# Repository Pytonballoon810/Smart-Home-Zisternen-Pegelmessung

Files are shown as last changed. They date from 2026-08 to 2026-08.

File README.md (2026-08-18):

# Zisternen-Pegelmessung

Continuous water level measurement for a garden cistern, using a hydrostatic
4–20 mA probe read by an ESP8266 and reported to Home Assistant via ESPHome.

Replaces a ten-contact float ladder that resolved 300 litres per step — too
coarse to answer the question that actually matters: *is there enough water for
tomorrow's irrigation, and how fast does the tank recover?*

---

## How it works

A 2-wire loop-powered probe sits near the bottom of the shaft and pushes 4 mA
when the water column is zero, 20 mA at full range. That current runs through a
100 Ω burden resistor, turning it into 0.400 V … 2.000 V, which a 16-bit
ADS1115 reads over I²C. ESPHome converts volts to centimetres, then to litres.

The reason for 4–20 mA rather than a voltage output: **a broken cable reads
0 mA, which is 0.000 V — clearly distinguishable from an empty tank at 4 mA.**
A voltage sensor cannot tell those apart, and a cistern that reports "empty"
because a mouse chewed the cable is worse than no sensor at all.

| State | Current | Voltage |
|---|--:|--:|
| Cable break | 0 mA | 0.00 V |
| Empty | 4 mA | 0.40 V |
| Full | 20 mA | 2.00 V |
| Short / overrange | 30 mA | 3.00 V |

---

## Repository layout

| Path | Contents |
|---|---|
| [`docs/hardware.md`](docs/hardware.md) | Bill of materials, wiring, how to choose a probe, installation in the shaft |
| [`docs/pcb-specification.md`](docs/pcb-specification.md) | Interface board: circuit, rationale, v1.0 → v1.1 change log |
| [`docs/calibration.md`](docs/calibration.md) | Two-point calibration procedure — **do not skip this** |
| [`docs/home-assistant.md`](docs/home-assistant.md) | Entities, dashboard cards, derived sensors, automations |
| [`docs/findings.md`](docs/findings.md) | Measured behaviour of an open-bottomed cistern |
| [`esphome/`](esphome/) | Device configuration and secrets template |
| [`hardware/`](hardware/) | KiCAD project, custom libraries, fabrication outputs |
| [`images/`](images/) | Photographs (shot list only — nothing built yet) |

---

## Status

| Part | State |
|---|---|
| ESPHome configuration | Written, not yet flashed |
| Interface PCB | Designed, routed, ERC/DRC clean — **not yet fabricated** |
| Probe and installation | Not yet purchased or built |
| Calibration | Pending installation |

Nothing here has been through a full build yet. The findings in
[`docs/findings.md`](docs/findings.md) come from the float ladder this project
replaces, not from the probe.

---

## Before you build one of these

**Get a vented probe.** The cable must contain a capillary venting the sensor
to atmosphere. Without it the probe measures water column *plus* barometric
pressure, and a normal weather system moves that by 20–30 cm of apparent water
— hundreds of litres of error that drifts rather than breaks. This is the single
most expensive mistake available here.

**The burden resistor sets your accuracy.** 100 Ω at 0.1 % and ≤50 ppm/K. A 1 %
part dominates every other error in the chain, including the probe's own.

**Calibrate in two points after installation.** The shipped transfer curve is
theoretical. Ten minutes with a multimeter and a tape measure is the difference
between an indication and a measurement.

**The v1.1 board has no input protection.** No fuse, no reverse-polarity diode,
no TVS — deliberately, to keep the part count at eight. Feed it from a
known-good supply and check polarity at J1. See §14 of the PCB specification
for what to reinstate if your installation is less forgiving than a dry shed.

---

## An honest caveat about open-bottomed cisterns

This cistern has an open bottom, in hydraulic contact with groundwater. That
makes it a **buffer, not a reservoir**: the level settles at the groundwater
table, rainfall above that drains away within hours, and the tank refills itself
after heavy draw-off. Measured recovery was roughly 600 litres in five hours.

The practical consequence is that usable storage is not the tank volume but the
gap between groundwater level and full — and that gap moves with the season, so
a fixed "ration below X litres" rule does not work.

[`docs/findings.md`](docs/findings.md) has the measurements. If your cistern is
sealed, none of it applies.

Groundwater abstraction is also regulated in most jurisdictions — in Germany
under the Wasserhaushaltsgesetz. Worth asking your local authority before
building something similar.

---

## Licence

Not yet chosen. Until one is added, treat this as "look, learn, but ask before
redistributing".

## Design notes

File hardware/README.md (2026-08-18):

# KiCAD project

The interface board itself. **The design is documented in
[`../docs/pcb-specification.md`](../docs/pcb-specification.md)** — circuit,
BOM, rationale and the v1.0 → v1.1 change log. This file covers only the
mechanics of working with the KiCAD project.

## Status

| Stage | State |
|---|---|
| Schematic | ERC **0 errors, 0 warnings** |
| Netlist | Verified against intent (8 nets) |
| Placement | No courtyard overlaps |
| Routing | 68 segments, 6 vias, **0 unconnected** |
| DRC | **0 errors** (5 cosmetic silkscreen warnings) |
| Fabrication outputs | Gerbers, drill, BOM, PDFs in `output/` |

The silkscreen warnings are U2's outline crossing the board edge, which is the
deliberate antenna overhang, plus reference designators overlapping the
connector labels.

## Layout

```
hardware/
  cistern-level-interface.kicad_pro   project (also carries the DRC floor)
  cistern-level-interface.kicad_sch   schematic
  cistern-level-interface.kicad_pcb   board
  fp-lib-table, sym-lib-table         point at lib/ — needed for the custom parts
  lib/cistern.kicad_sym               ADS1115_Breakout, MP1584_Module symbols
  lib/cistern.pretty/                 MP1584EN_Buck_Module footprint
  output/                             generated: Gerbers, drill, BOM, PDFs, render
```

`lib/cistern.pretty/Fuse_Bourns_MF-R025_Radial.kicad_mod` is unused in v1.1. It
is kept because the protected variant in the change log would need it.

## Custom parts

Both module footprints were built from the physical hardware, not datasheets:

- **MP1584EN** — 22.3 × 16.8 mm, four corner connections each doubled on
  2.54 mm pitch (8 holes), columns 19.05 mm apart. Top view: IN left, OUT
  right, `+` is the lower hole of each pair. Pad pitch still wants a caliper
  check before ordering.
- **ADS1115 (KY-053)** — plain 1×10 header on 2.54 mm, order VDD, GND, SCL,
  SDA, ADDR, ALRT, A0, A1, A2, A3. Confirmed against the module.

## Regenerating outputs

```bash
kicad-cli sch export pdf -o output/cistern-level-interface-schematic.pdf cistern-level-interface.kicad_sch
kicad-cli pcb export gerbers -o output/gerbers cistern-level-interface.kicad_pcb
kicad-cli pcb export drill -o output/gerbers/ cistern-level-interface.kicad_pcb
kicad-cli pcb drc --severity-error cistern-level-interface.kicad_pcb
```

## Re-routing

Routed with the [KiCADRoutingTools](https://github.com/drandyhaas/kicadroutingtools)
plugin, headless:

```bash
python route.py in.kicad_pcb out.kicad_pcb --layers F.Cu B.Cu --clearance 0.2 --track-width 0.25 --via-size 0.6 --via-drill 0.3 --power-nets "*GND*" "*19V*" "*5V*" "*3V3*" --power-nets-widths 0.8 0.8 0.5 0.5
```

Two rules from the plugin's own docs that are easy to get wrong:

- Copy boards with its `copy_board.py`, not `cp`. A bare copy strands the
  sibling `.kicad_pro` that carries the DRC floor, and KiCAD then grades
  correct copper as phantom violations.
- Route to a **fresh** output path each run. Re-using one makes `route.py` read
  back its own `.kicad_pro` and silently change the result.

Verify with all three — they check different things:

```bash
python check_connected.py out.kicad_pcb
python check_drc.py out.kicad_pcb --clearance 0.2 --clearance-margin 0.1
kicad-cli pcb drc --severity-error out.kicad_pcb
```

A DRC-clean board can be entirely disconnected; isolated copper has no
clearance conflicts.

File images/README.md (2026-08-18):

# Images

Empty for now — the installation is not built yet.

## Shot list

Photographs worth taking as the build progresses. Each answers a question that
text handles badly.

### Probe and shaft

- [ ] **Probe with the protective cap removed**, showing the diaphragm.
      Answers "which end actually measures" — the reference point for depth
      measurement during calibration.
- [ ] **Cable cross-section**, showing the capillary between the conductors.
      This is the detail people get wrong when buying; a photo settles it.
- [ ] **Probe suspended in the stilling tube**, before lowering.
      Shows the 20–30 cm standoff from the floor.
- [ ] **Shaft from above** with the probe installed and the junction box
      mounted near the top.

### Junction box

- [ ] **Interior**, showing where the capillary terminates and the
      pressure-equalising filter sits.
- [ ] **Mounting position** relative to the maximum water level.

### Electronics

- [ ] **Breadboard prototype** — useful precisely because it is untidy; it
      shows the circuit is only a handful of components.
- [ ] **Assembled interface board**, with both modules seated, before it goes
      in the enclosure.
- [ ] **MP1584 trimpot being set to 5.0 V** with the meter reading visible and
      the D1 mini socket still empty. This is the step that kills the ESP if
      done in the wrong order, so it is worth documenting.
- [ ] **Enclosure interior**, with terminal blocks, modules and the burden
      resistor visible.
- [ ] **Close-up of the burden resistor** with its markings legible.

### Home Assistant

- [ ] **Dashboard card** with a real level reading.
- [ ] **72-hour history graph** covering an irrigation cycle and the refill
      afterwards. This is the single most informative screenshot for anyone
      with an open-bottomed cistern — it shows the recovery curve directly.
- [ ] **Calibration**: multimeter across R1, ideally with the reading visible.

## Conventions

- Landscape, 1600 px wide is plenty
- Compress before committing; a repo does not need 4 MB photos
- Descriptive filenames: `probe-diaphragm.jpg`, not `IMG_2847.jpg`
- Reference from the docs as `![description](../images/filename.jpg)`

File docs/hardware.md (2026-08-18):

# Hardware

Bill of materials, wiring, and selection criteria.

---

## 1. Bill of materials

### Measurement chain

| Item | Specification | Qty | ~Cost |
|---|---|--:|--:|
| **Level probe** | 4–20 mA, 2-wire, 12–32 V DC, range to suit, stainless, IP68, **vented cable** | 1 | 40 € |
| **ADC module** | ADS1115, 16-bit, I²C (Joy-IT KY-053, sold as RB-ADC01) | 1 | 12 € |
| **Microcontroller** | ESP8266 (Wemos D1 mini) | 1 | 5–8 € |
| **Buck converter** | MP1584EN adjustable module, set to 5.0 V | 1 | 2 € |
| **Burden resistor** (R1) | 100 Ω, 0.1 %, metal film, ≤ 50 ppm/K, ≥ 0.25 W | 1 | 2 € |
| **Series limiter** (R2) | 1 kΩ, 1 %, 0402 — non-critical | 1 | <1 € |
| **Filter cap** (C3) | 100 nF C0G, 0805 | 1 | <1 € |
| **Interface PCB** | 70 × 60 mm, 2-layer — see [`pcb-specification.md`](pcb-specification.md) | 1 | ~5 € (qty 5) |
| **Power supply** | 19 V DC, ≥ 300 mA | 1 | 12–20 € |

The three discrete parts, two screw terminals and the two module sockets sit on
the interface PCB. On a breadboard, only R1 is strictly needed — see §3.

### Cable run (if the probe cable is too short)

| Item | Specification | Qty | ~Cost |
|---|---|--:|--:|
| **Junction box with pressure equalisation** | e.g. TECSON T12080, IP 64, Goretex filter | 1 | 27 € |
| Extension cable | 2-core, ≥ 0.4 mm² | as needed | 5 € |

### Installation

| Item | Specification | Qty | ~Cost |
|---|---|--:|--:|
| Stilling tube | HT pipe DN 50/75, drilled | ~2 m | 10 € |
| Pipe clamps | for shaft wall | 2–3 | 5 € |
| Suspension | stainless wire or UV-resistant ties | 1 | 3 € |
| Enclosure | IP65 | 1 | 15 € |
| Terminal blocks, glands, wire | — | 1 set | 10 € |

**Total: approximately 140 €.**

---

## 2. Choosing the probe

### Measurement range

Measure the **water column**, not the cistern's build height:

```
range = (overflow height) − (pump intake height)
```

A 3 m deep cistern typically has 2.2–2.5 m of usable column — the overflow sits
20–40 cm below the ceiling, the pump 20–30 cm above the floor.

Pick the next size up, not two. Accuracy is specified as a percentage of **full
scale**: 0.5 % on a 2 m probe is 10 mm, on a 5 m probe it is 25 mm.

Exceeding the range does not damage the probe — most tolerate several times
their rated pressure. The reading simply stops rising.

### Vented cable — mandatory

The specification must state one of:

- Luftführungskabel
- vented cable / air tube
- capillary / Kapillare
- gauge pressure (as opposed to absolute)

**Without it the probe measures absolute pressure**, i.e. water column *plus*
atmospheric pressure. A normal weather system moves barometric pressure by
20–30 hPa, equivalent to 20–30 cm of water column. In a 2 m diameter cistern
that is 600–900 litres of error.

The failure mode is insidious: nothing breaks, the reading just wanders slowly.

### Cable length

Measure from the intended probe position to the dry termination point, then add
two metres. Vented cable cannot be extended with ordinary connectors — the air
path must stay open. Either buy it long enough, or budget for a junction box
with a pressure-equalising filter.

### Material

Stainless 304 is adequate for rainwater. 316L only matters if chlorides are
present.

Prefer a **removable protective cap** — an open-bottomed cistern carries
sediment, and being able to clean the diaphragm without pulling the probe is
worth having.

---

## 3. Wiring

Minimum wiring, as on the breadboard prototype:

```
   19 V (+) ─────────────────────────────►  Probe (+)     [usually red]

   Probe (−) [usually black] ──┬─────────►  ADS1115  A0
                               │
                            R1 100 Ω
                               │
   19 V (−) ───────────────────┴─────────►  ADS1115  GND ──── ESP GND

   ESP 3V3 ──────────────────────────────►  ADS1115  VDD
   ESP D2 (GPIO4) ───────────────────────►  ADS1115  SDA
   ESP D1 (GPIO5) ───────────────────────►  ADS1115  SCL
```

The interface PCB adds two parts to this chain — **R2**, a 1 kΩ series resistor
between the burden node and A0, and **C3**, 100 nF from A0 to ground. Neither
affects the measurement: R2 limits current into the ADS1115's internal
protection diodes, and C3 filters the buck converter's switching noise. R2 sits
in a 1 kΩ : ~6 MΩ divider with the ADC input, contributing about 0.02 % gain
error, which the two-point calibration removes anyway. On a breadboard both can
be omitted.

The PCB also carries the MP1584 buck that derives 5 V for the ESP, so only one
supply is needed.

**Common ground is mandatory.** The ADS1115 measures against its own GND pin;
if that is not tied to the supply negative, the reading is undefined.

### Signal levels at 100 Ω

| State | Current | Voltage |
|---|--:|--:|
| Cable break | 0 mA | 0.00 V |
| Empty (probe top) | 4 mA | 0.40 V |
| Half (mid-range) | 12 mA | 1.20 V |
| Full (range top) | 20 mA | 2.00 V |
| Short / overrange | 30 mA | 3.00 V |

### Why 100 Ω and not 150 Ω

The ADS1115 input must stay below VDD + 0.3 V. Powered from 3.3 V that ceiling
is 3.6 V.

| Burden | Signal at 20 mA | Fault at 30 mA |
|---|--:|--:|
| 100 Ω | 2.00 V | 3.00 V ✅ |
| 150 Ω | 3.00 V | **4.50 V** ❌ |

150 Ω works if the ADS1115 runs at 5 V — but then the I²C bus sits at 5 V
against a 3.3 V microcontroller, which needs a level shifter. The extra
resolution is meaningless: both options resolve far finer than the probe.

### Supply voltage

The probe needs its minimum terminal voltage *plus* the burden drop:

```
supply ≥ probe_minimum + (0.020 A × burden)
       ≥ 12 V + 2 V  =  14 V
```

**This installation uses 19 V**, which leaves 17 V at the probe at full scale —
comfortable margin over the 12 V minimum, and within the MP1584's 4.5–28 V
input range. A surplus laptop brick is ideal; they are almost all 19 or 19.5 V
and rated far beyond the ~300 mA needed.

> ### ⚠ Check polarity before connecting
>
> The interface board has **no reverse-polarity protection** — the series
> Schottky was dropped in v1.1 to cut part count. Reversing J1 destroys the
> MP1584 and probably everything downstream of it.
>
> Laptop supplies often have **three** output conductors: V+, V− and a thin
> ID/sense wire the laptop uses to identify the adapter. Identify them with a
> meter before wiring — the pair reading ≈19 V DC are your rails, and the wire
> that floats or reads an odd, drifting voltage is the ID line, which is left
> unconnected. Check on **AC volts** too: any significant AC means it is a
> transformer, not a DC supply, and must not be connected.

---

## 4. Installation in the shaft

**Suspend the probe 20–30 cm above the floor**, do not rest it on the bottom.
Sediment accumulates, and a probe lying in silt eventually measures silt.

**Use a stilling tube** — a drilled HT pipe. It holds the probe in position and
shields it from flow when the pump runs.

**Terminate the cable dry.** The capillary's open end must sit in dry air, with
desiccant if the enclosure is not otherwise dry. If the run needs a junction in
the shaft, use a box with a pressure-equalising filter; an ordinary sealed box
would block the air path and defeat the vented cable entirely.

**Define zero at the pump intake**, not at the floor. Water below the intake
cannot be pumped and should not appear as available stock.

---

## 5. Litres per centimetre

```
litres_per_cm = π × (diameter / 2)² × 10
```

| Diameter | Area | Litres per cm |
|---|--:|--:|
| 1.5 m | 1.77 m² | 17.7 |
| 1.8 m | 2.54 m² | 25.4 |
| 2.0 m | 3.14 m² | 31.4 |
| 2.2 m | 3.80 m² | 38.0 |
| 2.5 m | 4.91 m² | 49.1 |

For non-cylindrical tanks, substitute the cross-sectional area. The ESPHome
configuration does this calculation from a `substitutions` entry — no code
changes needed.

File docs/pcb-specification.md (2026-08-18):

# PCB Specification — Cistern Level Sensor Interface

Interface board carrying the ESP8266 and ADS1115 modules, the burden resistor
and a 19 V to 5 V converter. Replaces the breadboard prototype for permanent
installation.

**Version:** 1.1 — 18 August 2026
**Status:** built, routed, ERC and DRC clean. Not yet fabricated.
**KiCAD project:** [`../hardware/`](../hardware/)

> **v1.1 is a deliberate simplification of v1.0.** The original specification
> called for a full input-protection chain and a split analogue/digital ground.
> Both were dropped. Section 14 records what changed and why — read it before
> assuming a part exists.

---

## 1. Purpose and scope

Carrier board that interfaces a 4–20 mA hydrostatic level probe to an ESP8266
running ESPHome, replacing the breadboard prototype for permanent installation
in a garden shed.

**Out of scope:** the probe, the junction box at the cistern shaft, the
enclosure, and external wiring.

### 1.1 Design philosophy

The board is a **carrier for three off-the-shelf modules**, not an integrated
design:

- Hand-solderable, no reflow or fine-pitch work
- Modules are individually replaceable if damaged in the field
- Avoids RF layout, antenna matching and USB design for the ESP
- Total assembly time under 30 minutes

This costs board area versus an integrated design. For a one-off in a shed,
that trade is worth making.

---

## 2. Functional requirements

| ID | Requirement | v1.1 |
|---|---|---|
| F1 | Accept a 2-wire 4–20 mA loop-powered probe, 12–32 V DC compliance | ✅ met |
| F2 | Convert loop current to a voltage readable by a 16-bit ADC | ✅ met |
| F3 | Single-supply operation from one DC input | ✅ met (19 V) |
| F4 | Distinguish cable break (0 mA) from empty tank (4 mA) | ✅ met |
| F5 | Survive a probe short circuit (≥ 30 mA) without damage | ⚠️ partial — see §5.3 |
| F6 | Survive reverse polarity on the input without damage | ❌ **descoped** |
| F7 | Break out unused ADC channels for future expansion | ❌ descoped |
| F8 | Provide test points for two-point calibration in situ | ❌ descoped — probe R1 directly |

F5 is partial rather than failed: a 30 mA probe fault still produces only 3.0 V
at the burden, which the ADS1115 tolerates (§3.3). What is gone is protection
against surge and gross overvoltage.

---

## 3. Electrical specification

### 3.1 Supply

| Parameter | Value |
|---|---|
| Input voltage | 19 V DC nominal (4.5–28 V accepted by U1) |
| Input current | ~100 mA typical, 300 mA supply recommended |
| Reverse polarity | **Not protected** |
| Internal rails | 5 V (MP1584 buck), 3.3 V (D1 mini onboard LDO) |

### 3.2 Measurement chain

| Parameter | Value |
|---|---|
| Loop current range | 4–20 mA (0–30 mA without damage) |
| Burden resistor | 100 Ω, 0.1 %, ≤ 50 ppm/K, ≥ 0.25 W |
| Signal at burden | 0.400 V (4 mA) … 2.000 V (20 mA) |
| Fault signal | 0.000 V (break), 3.000 V (30 mA short) |
| ADC | ADS1115, 16 bit, gain ±4.096 V, 125 µV/LSB |
| Effective resolution | ≈ 12 800 counts over range |

> **The burden resistor sets system accuracy.** Its tolerance appears directly
> in the reading. A 1 % part would dominate the probe's own 0.2–0.5 % error.
> Metal film, not carbon — carbon drifts up to 1000 ppm/K and the shed sees
> −10 to +40 °C.

### 3.3 ADC supply decision

**ADS1115 runs from 3.3 V, not 5 V.**

Its input must stay below VDD + 0.3 V. At 3.3 V that ceiling is 3.6 V; the
worst-case fault signal is 3.0 V, leaving 0.6 V of margin. Running from 3.3 V
also puts the I²C bus natively at ESP level, so **no level shifter is
required**.

Running the ADC at 5 V would allow a 150 Ω burden and marginally better
resolution, at the cost of a level shifter or an out-of-spec I²C connection.
The extra resolution is meaningless — the probe is two orders of magnitude
coarser than either option.

---

## 4. Block diagram

```
  19 V DC in (J1)
      │
      ├──────────────────────────────────► J2.1  Probe (+)  [LOOP+]
      │
   [U1  MP1584EN buck 19→5 V]
      │
      5 V ──► D1 mini (5V pin) ──► onboard LDO ──► 3.3 V ──► ADS1115 VDD
                    │                                            │
                    └──────────── I²C (SDA/SCL, 3.3 V) ──────────┘
                                                                 │
  J2.2  Probe (−) ──┬────── [R2 1 k] ──┬──────────────────► ADS1115 A0
     [LOOP-]        │                  │
                 [R1 100 Ω]        [C3 100 nF]
                    │                  │
                   GND ──────────────  GND
```

Single ground net, poured on both layers — see §10.

---

## 5. Circuit detail

### 5.1 Input

No protection components. J1 feeds U1's input and J2.1 directly.

> **This is the deliberate compromise of v1.1.** There is no fuse, no series
> diode and no TVS. Feed the board only from a known-good 19 V supply and check
> polarity at J1 before every power-up. If the board is ever moved somewhere
> with a long buried supply run, revisit §14.

### 5.2 Buck converter

**U1 — MP1584EN adjustable module**, 4.5–28 V in, adjustable out, ~3 A capable.

> ### ⚠ Set U1 to 5.0 V before fitting U2
>
> The MP1584's output is set by a multi-turn trimpot, and the as-shipped
> setting is arbitrary — often well above 5 V. Power the board with the D1 mini
> socket **empty**, set the output to 5.0 V with a meter, then fit the ESP.
> This is silkscreened on the board.

A 7805 linear regulator will not do: 19 V in, 5 V out at 200 mA is 2.8 W of
dissipation in a sealed enclosure.

### 5.3 Measurement front end

| Ref | Part | Function |
|---|---|---|
| R1 | 100 Ω, 0.1 %, ≤50 ppm/K, 0.25 W metal film, axial | **Burden** — converts loop current to voltage |
| R2 | 1 kΩ, 1 %, 0402 | Series limit into the ADC's internal protection diodes |
| C3 | 100 nF, C0G, 0805 | Anti-alias / buck-noise filter, τ = 100 µs with R2 |

R2 and C3 form a low-pass at 1.6 kHz. The signal is quasi-static — a cistern
level changes over hours — so this costs nothing and removes switching noise
from the buck. That matters more here than it would have with the v1.0 Recom
module: the MP1584 is a noisier switcher.

**Neither R2 nor C3 affects accuracy.** R2 sits in a 1 kΩ : ~6 MΩ divider with
the ADS1115 input, contributing about 0.02 % gain error — and that is a
systematic gain term, which the two-point `calibrate_linear` removes outright.
R2 carries under a microamp and dissipates around a nanowatt, so its tolerance,
dielectric and power rating are all irrelevant. R1 is the opposite in every
respect.

---

## 6. Connectors and interfaces

| Ref | Type | Pins | Function |
|---|---|---|---|
| J1 | Screw terminal, 5.08 mm | 2 | 19 V DC input — silkscreened `+19V` / `GND` |
| J2 | Screw terminal, 5.08 mm | 2 | Probe loop — silkscreened `LOOP+` / `LOOP−` |
| U1 | Module, 8 holes in 4 corner pairs | — | MP1584EN buck |
| U2 | Socket header, 2 × 1×8 | 16 | D1 mini |
| U3 | Socket header, 1×10 | 10 | KY-053 ADS1115, `VDD` and `A3` ends marked |

> **J2 polarity is silkscreened**, and it matters: the probe is 2-wire loop
> powered, and reversing it reads 0 mA — indistinguishable from a cable break
> at the ESPHome level.

### 6.1 Module orientation

**U3's body overhangs one side of its header** by about 15 mm. It must face
*away* from U2 — there is only 7.4 mm of clearance toward the ESP but 22 mm on
the other side, where it passes over R1/R2/C3, all low enough to sit under a
socketed module. The board is silkscreened `U3 BODY THIS SIDE (NOT TOWARD U2)`.

**U2's body overhangs the top board edge** by about 5 mm, deliberately: that is
the antenna end, and copper is kept clear beneath it.

---

## 7. Bill of materials

| Ref | Part | Package | Qty | Notes |
|---|---|---|--:|---|
| U1 | MP1584EN buck module | 22.3 × 16.8 mm, 8 THT holes | 1 | **Set to 5.0 V first** |
| U2 | Wemos D1 mini (ESP8266) | Module on sockets | 1 | |
| U3 | Joy-IT KY-053 (ADS1115) | Module on 1×10 socket | 1 | Also sold as RB-ADC01 |
| R1 | 100 Ω, 0.1 %, ≤50 ppm/K | Axial DIN0207, 10.16 mm | 1 | **Accuracy-critical** |
| R2 | 1 kΩ, 1 % | 0402 | 1 | Non-critical |
| C3 | 100 nF, C0G | 0805 | 1 | |
| J1, J2 | Screw terminal 5.08 mm | 2-pin | 2 | |
| H1–H4 | M3 mounting holes | 3.2 mm | 4 | NPTH |

Eight placed parts. Estimated component cost excluding the three modules:
**under 5 €.**

---

## 8. Mechanical

| Parameter | Value |
|---|---|
| Board outline | 70 × 60 mm |
| Thickness | 1.6 mm |
| Mounting | 4 × M3, 3.2 mm dia., 5 mm in from each corner |
| Component height | ≤ 20 mm (D1 mini on sockets is tallest) |
| Connector edge | J1 and J2 along one long edge for cable entry |

Terminal blocks on a single edge simplify cable glanding — the enclosure needs
penetrations on one side only.

---

## 9. Fabrication

| Parameter | Specification |
|---|---|
| Layers | 2 |
| Material | FR-4, TG 130 or better |
| Copper weight | 1 oz (35 µm) |
| Min trace / space | 0.25 mm signal, 0.2 mm clearance |
| Min drill | 0.3 mm (vias), 1.0 mm (module holes) |
| Surface finish | HASL lead-free, or ENIG |
| Solder mask | Green, both sides |
| Silkscreen | White, top side |

Within standard capability at JLCPCB, Aisler and PCBWay. No controlled
impedance, no blind or buried vias, no special stackup.

**Quantity:** 5 pieces is the typical minimum and costs about the same as 1–2.

Gerbers and drill files are exported to
[`../hardware/output/gerbers/`](../hardware/output/gerbers/).

---

## 10. Layout, as routed

| Parameter | Value |
|---|---|
| Signal tracks | 0.25 mm |
| GND, +19 V | 0.8 mm |
| +5 V, +3V3 | 0.5 mm |
| Vias | 0.6 mm outer / 0.3 mm drill, 6 used |
| Clearance | 0.2 mm |
| Segments | 68 |

Routed with the [KiCADRoutingTools](https://github.com/drandyhaas/kicadroutingtools)
plugin's headless `route.py`.

**Ground is a single net, poured on both F.Cu and B.Cu.** v1.0 called for split
AGND/DGND joined at a star point; §14 explains why that was dropped.

Layout intent worth preserving if the board is ever re-laid:

1. Analogue parts (R1, R2, C3, U3) grouped in one corner, ≥ 15 mm from the ESP
   antenna. As built the separation is over 30 mm.
2. No copper under the D1 mini's antenna, which overhangs the top edge.
3. Keep the ground pour continuous between U3 and R1 — it is what makes the
   return path short (§11).

---

## 11. Grounding

The v1.0 concern was that the burden's return current would share a narrow
ground **trace** with the ESP: 200 mA of WiFi burst through 10 mΩ of shared
copper is 2 mV, or 0.12 % of full scale — comparable to the probe's entire
tolerance, given away by a layout shortcut. v1.0 answered it with separate AGND
and DGND pours joined by a 0 Ω link at the buck output.

v1.1 answers it with a **solid pour on both layers** instead. Return current in
a plane concentrates under its own outgoing trace, and the spreading resistance
between U2's ground and the analogue corner is well under a milliohm —
roughly 0.1 mV at 200 mA, some twenty times better than the trace case. The
star-point resistor became redundant and was removed.

The consequence: **do not fragment the pour** between U3 and R1. The plane is
doing the work the star link used to.

---

## 12. Verification

### 12.1 Board bring-up, before fitting modules

| Step | Check | Pass criteria |
|---|---|---|
| 1 | Visual, solder bridges | None |
| 2 | Resistance J1+ to J1− | > 10 kΩ (no short) |
| 3 | Apply 19 V, measure U1 output | Adjust trimpot to 5.00 V ± 0.05 V |
| 4 | Confirm 5 V at U2's 5V socket pin | 4.95–5.05 V |

**Step 3 is not optional and must precede fitting U2.**

### 12.2 With modules fitted

| Step | Check | Pass criteria |
|---|---|---|
| 5 | I²C scan in ESPHome log | Device found at 0x48 |
| 6 | Inject 4.00 mA into J2 | 0.400 V across R1 ± 0.5 mV |
| 7 | Inject 20.00 mA into J2 | 2.000 V across R1 ± 2 mV |
| 8 | Open J2 | 0 V across R1, fault sensor active |

Steps 6–7 need a current source; a bench supply with current limit and a series
ammeter is adequate. If unavailable, substitute a precision resistor across the
loop and calculate.

### 12.3 Calibration after installation

Two-point, measuring across R1 — see [`calibration.md`](calibration.md). This
corrects burden tolerance, probe offset and ADC gain error in one step. **Do not
skip it** — the theoretical curve is a starting point, not a calibration.

---

## 13. Open items

| Item | Notes |
|---|---|
| U1 pad pitch | Reconstructed from a photo of the actual module (22.3 × 16.8 mm, corner pairs on 2.54 mm, columns 19.05 mm apart). **Confirm with calipers before ordering.** |
| Enclosure selection | Determines final mounting |
| Cistern inner diameter | Needed for litre conversion, not for the PCB |
| Probe intake height | Defines zero point, not for the PCB |

U3's pinout was confirmed against the physical module and is no longer open.

---

## 14. What changed from v1.0, and why

v1.0 specified 21 placed parts on an 80 × 60 mm board. v1.1 has 8 on 70 × 60 mm.
The driver was a deliberate decision to let the modules do the work and keep
only what earns its place.

| Dropped | v1.0 rationale | Why it went |
|---|---|---|
| F1 PTC, D1 Schottky | Fault current limit, reverse polarity | Supply is a known-good brick in a dry shed; polarity is silkscreened and checked at commissioning |
| D2 TVS 33 V, D3 TVS 5 V | Surge from the buried probe cable | Accepted risk. **The one to reinstate first** if the board ever sees a long outdoor run |
| C1 100 µF, C2 100 nF | Bulk and HF decoupling | Redundant — the MP1584 module carries its own input and output capacitors |
| R3 0 Ω star link | Single AGND↔DGND connection | Superseded by the solid two-layer pour (§11) |
| TP1–TP4 | In-situ calibration points | R1 is an axial part; its leads take meter probes directly |
| J3 spare ADC breakout | F7 future expansion | Not needed; A1–A3 remain unconnected at U3 |
| J4 I²C expansion header | Future sensors | Not needed |

| Changed | v1.0 | v1.1 |
|---|---|---|
| Supply | 24 V | **19 V** — surplus laptop brick |
| Buck | Recom R-78E5.0-0.5, fixed 5 V | **MP1584EN**, adjustable — cheaper, but must be preset |
| Ground | Split AGND/DGND + star link | Single net, poured both layers |
| Board | 80 × 60 mm | 70 × 60 mm |

**The honest summary:** v1.1 trades robustness for simplicity. In a dry shed on
a known supply that is a reasonable trade. It would not be for an outdoor
enclosure, a shared supply rail, or a site with overhead power nearby.

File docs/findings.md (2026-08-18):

# Findings — behaviour of an open-bottomed cistern

Measured observations from a concrete cistern with an **open bottom**, i.e. in
hydraulic contact with groundwater. If your cistern is sealed, none of this
applies to you — skip this document.

Data collected August 2026 with a ten-contact float ladder (300 L resolution).
Numbers are therefore coarse; a continuous probe will refine them.

---

## The short version

An open bottom is a **buffer, not a reservoir.**

- Water level settles at groundwater height and will not rise above it for long
- Rainfall above that level drains away within hours
- After heavy draw-off, the level recovers on its own
- The equilibrium level itself tracks groundwater, which rises after rain

The practical consequence: usable storage is not the tank volume, but the
difference between groundwater level and full — and that difference changes
with the season.

---

## Observation 1 — recovery after running dry

On 11 August the irrigation system drained the cistern until the pump ran dry.
No further draw-off occurred afterwards (supply was switched to mains).

| Time | Level | Elapsed |
|---|--:|--:|
| 11.08. 11:27 | empty | — |
| 11.08. ~16:51 | ≥ 600 L | ~5 h |
| 13.08. 08:57 | 900 L | ~45 h |
| 13.–16.08. | 900 L | no change |

**Inflow rate falls as the level approaches equilibrium** — roughly 100 L/h
initially, about 8 L/h over the final 300 litres, then zero.

This is the expected Darcy behaviour: flow is proportional to the pressure
difference, which vanishes as the levels equalise.

**The practical implication is favourable.** A sealed cistern that runs dry
stays dry until it rains. This one had 600 litres back within five hours.

---

## Observation 2 — rainfall is only partly retained

21.3 mm of rain on 16 August:

| Time | Level | |
|---|--:|---|
| 16.08. 12:00 | 900 L | before rain |
| 16.08. 19:15 | 1200 L | filling |
| 16.08. **19:50** | **1500 L** | peak |
| 16.08. **22:25** | **1200 L** | ← fell back |
| 17.08. through 18.08. | 1200 L | stable |

**300 litres drained away in 2.5 hours with no water drawn.** The meter on the
outlet confirmed zero consumption during that window.

But the level settled at 1200 L, not the previous 900 L. The rain had also
**raised the groundwater table**, moving the equilibrium point up with it.

Net effect of this event: roughly 300 L retained, 300 L lost. Heavier rain
would lose a larger share, because the peak sits further above equilibrium.

---

## Observation 3 — draw-off is masked at high inflow

On 18 August the irrigation cycle drew 131 litres while 5.9 mm of rain fell.
**The level did not drop measurably.** Inflow matched the draw during the cycle
itself.

Under these conditions the tank behaves as though it had unlimited supply. That
holds only while groundwater is high.

---

## What this means for system design

### Storage is capped, not by volume, but by groundwater level

A 3000 litre tank sitting in groundwater at the 900 litre mark has 900 litres
of reliable stock and 2100 litres of unusable headroom. Rainfall filling that
headroom drains within hours.

### Do not seal the bottom without weighing the trade

Sealing it would capture the full 3000 litres — but remove the recovery. Three
weeks without rain in July is normal, and the observed recovery of 600 litres
in five hours is worth more than storage that only fills when it rains anyway.

If storage is the constraint, **additional tanks** are cheaper and lower-risk
than retrofitting a floor. Two 1000 litre IBC totes cost around 200 € and
capture exactly the water that currently drains away. Sealing an existing
cistern is expensive, and in high groundwater it can create buoyancy problems.

### A fixed low-level threshold does not work

Because the equilibrium point moves — 900 L in dry weather, 1500 L after rain —
any fixed "ration below X litres" rule is sometimes too aggressive and
sometimes ineffective.

Better approaches, in increasing order of complexity:

1. Threshold set from the observed dry-weather equilibrium, updated seasonally
2. Rate-of-change: ration when the level falls faster than it recovers
3. Predictive: compare tomorrow's requirement against level plus expected inflow

None of these are implemented here yet — a continuous probe is a prerequisite,
since 300 litre steps cannot resolve a recovery rate.

### Water quality

Groundwater is harder than rainwater and may carry iron and manganese, both of
which precipitate on contact with air and clog drip emitters. Two observations
in this installation are consistent with that: a greenhouse drip line fell from
1.02 to 0.56 L/min over a few days, and the outlet flow meter's impeller has
jammed on debris before.

Sediment ingress through an open bottom is the likely mechanism for both.

---

## Method notes

**Resolution was the limiting factor.** A 300 litre step cannot resolve a
recovery rate; the numbers above are bounds, not measurements. This is precisely
why the installation is moving to a continuous probe.

**Draw-off was independently verified** by a flow meter on the outlet, so
"no consumption" periods are confirmed rather than assumed.

**One confounder remains:** it is not possible to separate roof runoff from
groundwater inflow with a single level sensor. Both raise the level. Separating
them would need a flow meter on the inlet — worth having if the question
matters to you.

---

## Legal note

Groundwater abstraction is regulated in most jurisdictions. In Germany it falls
under the Wasserhaushaltsgesetz and is generally subject to permit, with
exemptions for small domestic quantities that vary by state and district.

An open-bottomed cistern in contact with groundwater is arguably abstraction.
This is not legal advice — if you are planning something similar, ask your
local water authority first.

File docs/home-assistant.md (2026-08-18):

# Home Assistant integration

Entities exposed by the device, dashboard cards, derived sensors and
automations.

---

## 1. Entities

Once the device is adopted, ESPHome exposes:

| Entity | Unit | Purpose |
|---|---|---|
| `sensor.zisterne_pegel_zisterne_fuellstand` | L | **Primary value** — usable stock |
| `sensor.zisterne_pegel_zisterne_fuellstand_prozent` | % | For gauges |
| `sensor.zisterne_pegel_zisterne_wassersaeule` | cm | Water column above probe |
| `sensor.zisterne_pegel_zisterne_nutzbare_hoehe` | cm | Column above pump intake |
| `sensor.zisterne_pegel_sonde_rohspannung` | V | Diagnostic — for calibration |
| `binary_sensor.zisterne_pegel_zisterne_sonde_stoerung` | — | Cable break or overrange |

Entity IDs depend on the device name in your ESPHome config. Adjust the
examples below accordingly.

---

## 2. Dashboard cards

### Gauge

```yaml
type: gauge
entity: sensor.zisterne_pegel_zisterne_fuellstand_prozent
name: Zisterne
min: 0
max: 100
severity:
  green: 50
  yellow: 25
  red: 0
needle: true
```

> Severity thresholds are worth setting from your own consumption, not from
> percentages. If a full irrigation cycle uses 670 L and the tank holds 3000 L,
> then 25 % is one cycle's worth — which is the number that actually matters.

### Level with history

```yaml
type: vertical-stack
cards:
  - type: entities
    title: Zisterne
    entities:
      - entity: sensor.zisterne_pegel_zisterne_fuellstand
        name: Vorrat
      - entity: sensor.zisterne_pegel_zisterne_wassersaeule
        name: Wassersäule
      - entity: binary_sensor.zisterne_pegel_zisterne_sonde_stoerung
        name: Sonde

  - type: history-graph
    hours_to_show: 72
    entities:
      - sensor.zisterne_pegel_zisterne_fuellstand
```

72 hours is a useful default: long enough to show a refill curve after an
irrigation cycle, short enough to read.

### Diagnostic card

Keep this somewhere out of the way — it is for commissioning and fault-finding,
not daily use.

```yaml
type: entities
title: Zisterne Sonde — Diagnose
entities:
  - entity: sensor.zisterne_pegel_sonde_rohspannung
    name: Rohspannung
  - entity: sensor.zisterne_pegel_zisterne_nutzbare_hoehe
    name: Höhe über Ansaugung
  - entity: sensor.zisterne_pegel_wifi_signal_db
    name: WLAN
  - entity: sensor.zisterne_pegel_uptime
    name: Laufzeit
```

The raw voltage is what you read during calibration. Having it on a card saves
climbing to the shed with a multimeter every time.

---

## 3. Derived sensors

### Refill rate

How fast the tank recovers. For an open-bottomed cistern this is the
groundwater inflow; for a sealed one it is roof runoff.

Create a **Derivative** helper:

| Field | Value |
|---|---|
| Source | `sensor.zisterne_pegel_zisterne_fuellstand` |
| Precision | 0 |
| Time window | 1 hour |
| Unit | L/h |

> Use a long time window. With a short one the derivative is dominated by
> sensor noise; the level itself changes over hours.

A **negative** value during an irrigation cycle is consumption. A **positive**
one afterwards is recovery — that is the number that tells you whether
tomorrow's cycle can run.

### Days of stock remaining

Requires a known daily consumption. If you have a flow meter on the outlet,
use its daily total; otherwise substitute your calculated irrigation demand.

```yaml
template:
  - sensor:
      - name: "Zisterne Reichweite"
        unit_of_measurement: "d"
        state: >
          {% set vorrat = states('sensor.zisterne_pegel_zisterne_fuellstand') | float(0) %}
          {% set bedarf = states('sensor.bewaesserung_bedarf_heute') | float(0) %}
          {% if bedarf > 0 %}
            {{ (vorrat / bedarf) | round(1) }}
          {% else %}
            unknown
          {% endif %}
```

This ignores refill, so it is a worst case. For an open-bottomed cistern that
is conservative by a wide margin.

---

## 4. Automations

### Low level warning

```yaml
alias: Zisterne — Vorrat niedrig
triggers:
  - trigger: numeric_state
    entity_id: sensor.zisterne_pegel_zisterne_fuellstand
    below: 500
    for: "00:15:00"
actions:
  - action: notify.mobile_app_your_phone
    data:
      title: Zisterne
      message: >
        Vorrat bei {{ states('sensor.zisterne_pegel_zisterne_fuellstand') }} L.
        Bewässerung reicht noch etwa
        {{ states('sensor.zisterne_reichweite') }} Tage.
mode: single
```

The `for: 15 minutes` matters — it prevents an alert while a pump is briefly
drawing the level down past the threshold.

### Probe fault

```yaml
alias: Zisterne — Sonde gestört
triggers:
  - trigger: state
    entity_id: binary_sensor.zisterne_pegel_zisterne_sonde_stoerung
    to: "on"
    for: "00:05:00"
actions:
  - action: notify.mobile_app_your_phone
    data:
      title: Zisterne Sonde
      message: >
        Signal außerhalb des gültigen Bereichs
        ({{ states('sensor.zisterne_pegel_sonde_rohspannung') }} V).
        Kabelbruch oder Sondendefekt.
mode: single
```

Under 0.3 V means less than 4 mA — a cable break. Over 2.3 V means more than
20 mA — overrange or a short. Either way the level reading is not trustworthy
until resolved.

### Dry-run protection

**This is the one that pays for the whole project.**

Without it, a pump that runs dry keeps running. In this installation it
cycled at its pressure switch for 65 minutes — 500 to 630 W with drops to 1 W
every few seconds — because no pressure could build. That is considerably worse
for a submersible pump than steady dry running.

```yaml
alias: Zisterne leer — Pumpe schützen
triggers:
  - trigger: numeric_state
    entity_id: sensor.zisterne_pegel_zisterne_fuellstand
    below: 50
actions:
  - action: switch.turn_off
    target:
      entity_id: switch.your_pump_socket
  - action: input_boolean.turn_on
    target:
      entity_id: input_boolean.zisterne_leer
  - action: notify.mobile_app_your_phone
    data:
      title: Zisterne leer
      message: Pumpe abgeschaltet. Auf Hauswasser umstellen.
mode: single
```

Two details that are easy to get wrong:

**Set the flag before switching off.** If an "always on" automation watches the
pump socket, it will switch it straight back on. The flag has to block that
automation, and it has to be set first.

**Do not clear the flag automatically** when the level recovers. An
open-bottomed cistern refills within hours, so the pump would restart into a
tank that has 200 litres in it. Clear it manually, or require the level to
exceed a much higher threshold.

If you have no level sensor yet, the same protection can be built from a flow
meter: pump drawing power but no flow for three minutes means either an empty
tank or a jammed meter — both require stopping.

---

## 5. Cross-check against a float ladder

If you are replacing float switches, keep them for a few weeks. The contacts
sit at known heights, so every transition is a free calibration point.

```yaml
type: history-graph
hours_to_show: 168
entities:
  - sensor.zisterne_pegel_zisterne_fuellstand
  - sensor.old_float_ladder_level
```

Plotted together, the probe should step through the ladder's levels at the same
moments. A consistent offset means the calibration zero is out; a consistent
slope difference means the span is.

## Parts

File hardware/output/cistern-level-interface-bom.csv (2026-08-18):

Ref | Value | Footprint | Qty
C3 | 100nF C0G | Capacitor_SMD:C_0805_2012Metric_Pad1.18x1.45mm_HandSolder | 1
J1 | 19V DC IN | TerminalBlock_Phoenix:TerminalBlock_Phoenix_MKDS-1,5-2-5.08_1x02_P5.08mm_Horizontal | 1
J2 | PROBE 4-20mA | TerminalBlock_Phoenix:TerminalBlock_Phoenix_MKDS-1,5-2-5.08_1x02_P5.08mm_Horizontal | 1
R1 | 100R 0.1% 50ppm | Resistor_THT:R_Axial_DIN0207_L6.3mm_D2.5mm_P10.16mm_Horizontal | 1
R2 | 1k 1% 0402 | Resistor_SMD:R_0402_1005Metric_Pad0.72x0.64mm_HandSolder | 1
U1 | MP1584EN | cistern:MP1584EN_Buck_Module | 1
U2 | WEMOS D1 mini | RF_Module:WEMOS_D1_mini_light | 1
U3 | KY-053 ADS1115 | Connector_PinHeader_2.54mm:PinHeader_1x10_P2.54mm_Vertical | 1

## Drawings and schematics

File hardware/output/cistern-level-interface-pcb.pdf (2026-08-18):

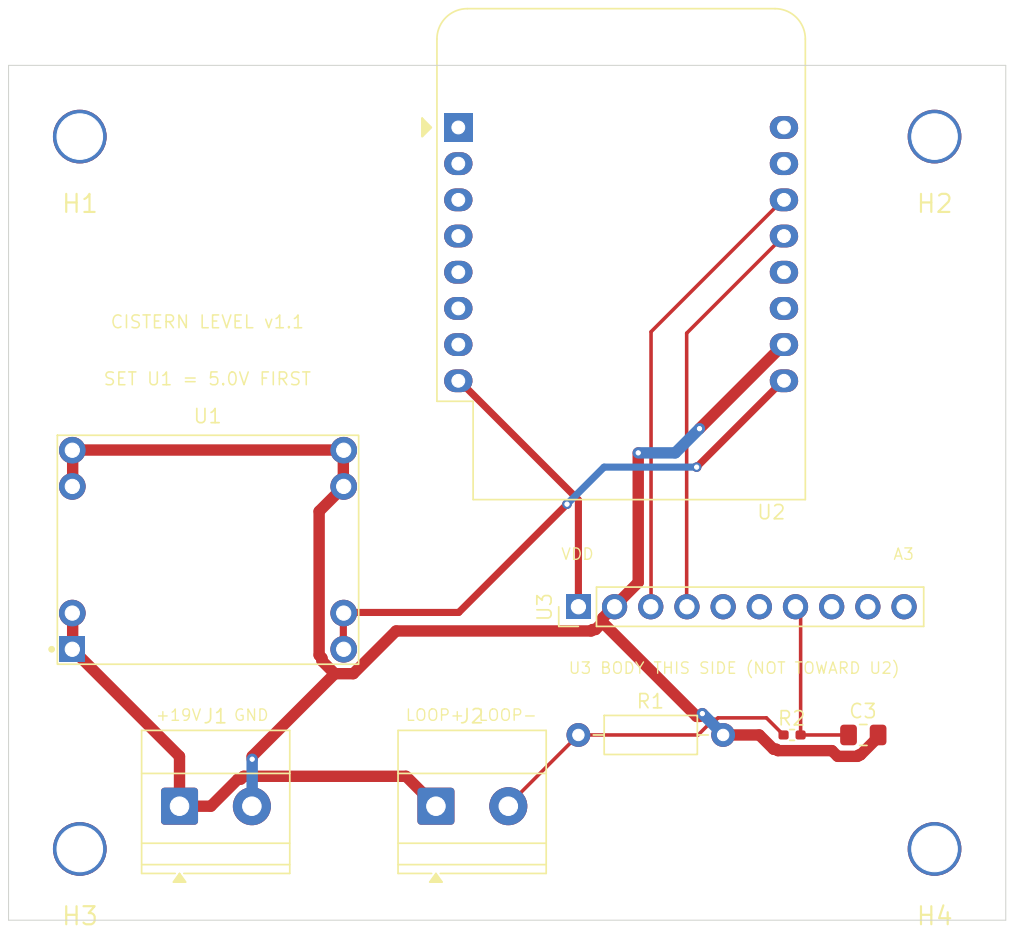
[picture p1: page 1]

SET U1 = 5.0V FIRST CISTERN LEVEL v1.1

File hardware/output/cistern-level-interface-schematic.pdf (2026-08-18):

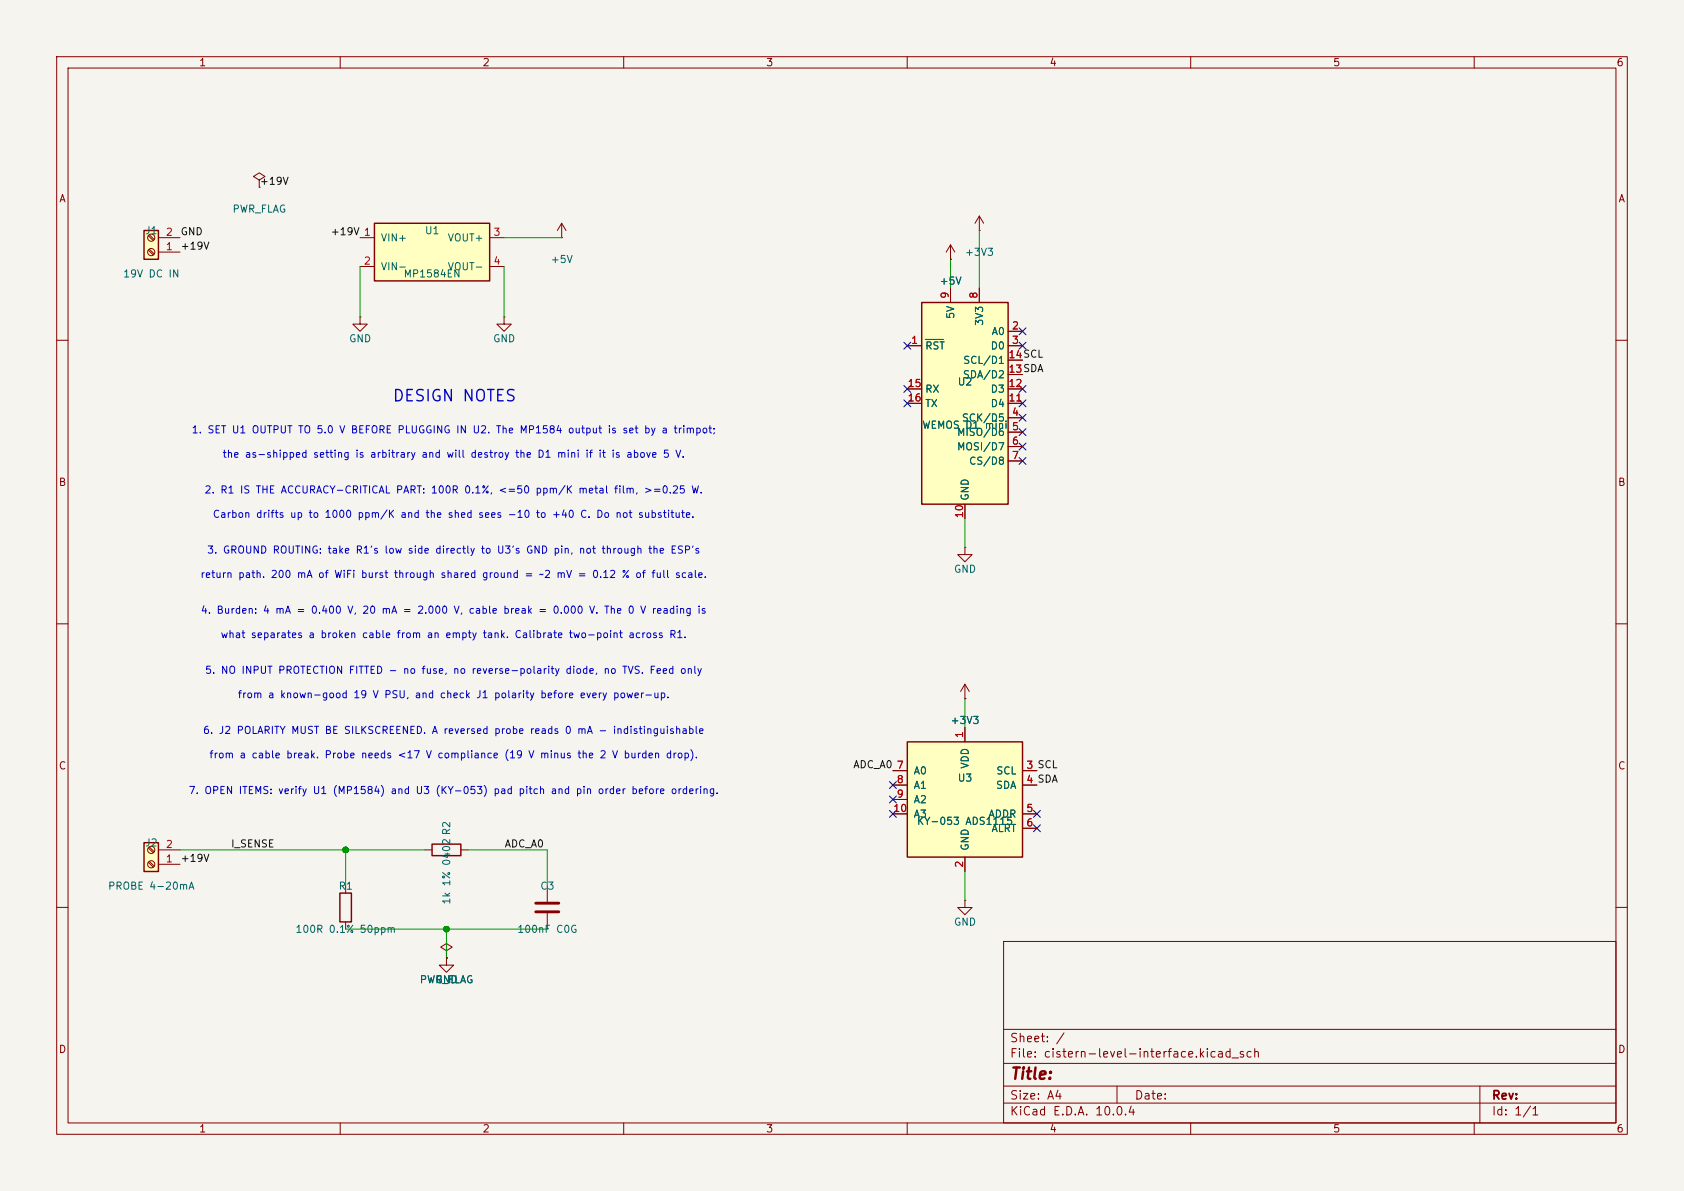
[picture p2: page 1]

8 5V 9 GND 10 D4 11 D3 12 SDA/D2 13 SCL/D1 14 RX 15

the as-shipped setting is arbitrary and will destroy the D1 mini if it is above 5 V. DESIGN NOTES

return path. 200 mA of WiFi burst through shared ground = ~2 mV = 0.12 % of full scale. 4. Burden: 4 mA = 0.400 V, 20 mA = 2.000 V, cable break = 0.000 V. The 0 V reading is 5. NO INPUT PROTECTION FITTED - no fuse, no reverse-polarity diode, no TVS. Feed only 6. J2 POLARITY MUST BE SILKSCREENED. A reversed probe reads 0 mA - indistinguishable 1. SET U1 OUTPUT TO 5.0 V BEFORE PLUGGING IN U2. The MP1584 output is set by a trimpot; from a known-good 19 V PSU, and check J1 polarity before every power-up. from a cable break. Probe needs <17 V compliance (19 V minus the 2 V burden drop). what separates a broken cable from an empty tank. Calibrate two-point across R1. PWR_FLAG GND

Carbon drifts up to 1000 ppm/K and the shed sees -10 to +40 C. Do not substitute. 2. R1 IS THE ACCURACY-CRITICAL PART: 100R 0.1%, <=50 ppm/K metal film, >=0.25 W. 3. GROUND ROUTING: take R1's low side directly to U3's GND pin, not through the ESP's

Sheet: /
File: cistern-level-interface.kicad_sch
Title:

Size: A4 | Rev:
KiCad E.D.A. 10.0.4 | Id: 1/1

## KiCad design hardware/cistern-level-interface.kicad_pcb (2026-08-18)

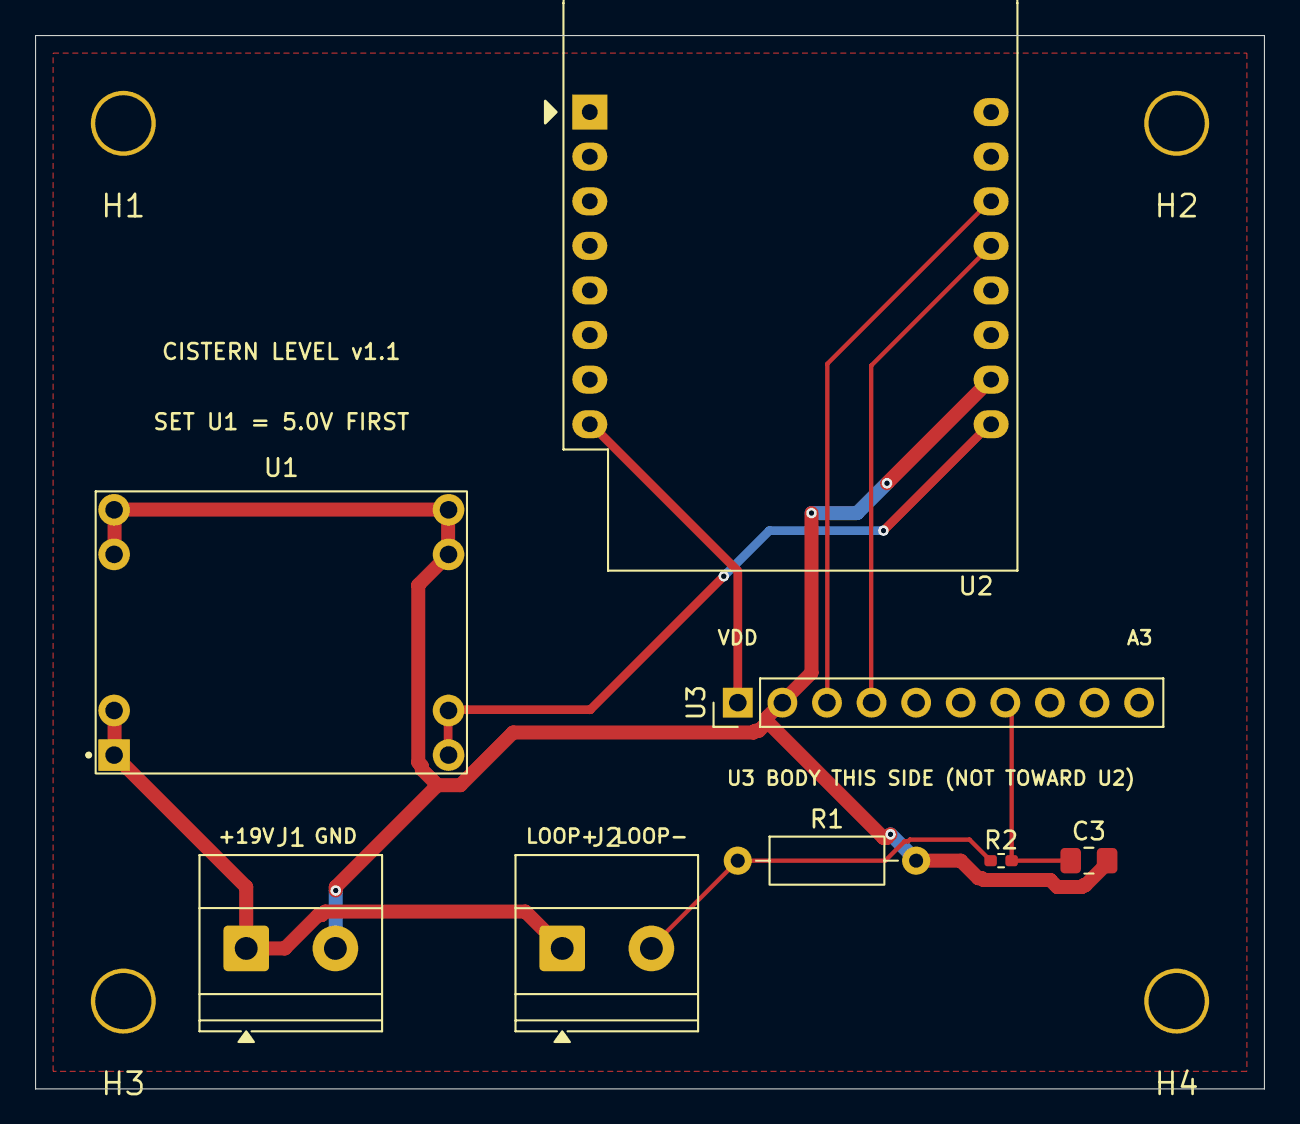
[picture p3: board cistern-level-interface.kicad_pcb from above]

Board: 2 copper layers, 70.0 x 60.0 mm, 12 parts (0 on the bottom side), 8 nets.

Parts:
C3: C_0805_2012Metric_Pad1.18x1.45mm_HandSolder
H1, H2, H3, H4: MountingHole; MountingHole_3.2mm
J1, J2: TerminalBlock_Phoenix_MKDS-1,5-2-5.08_1x02_P5.08m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; TerminalBlock_Phoenix_MKDS-1,5-2-5.08_1x02_P5.08mm_Horizont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
R1: R_Axial_DIN0207_L6.3mm_D2.5mm_P10.16mm_Horizontal
R2: R_0402_1005Metric_Pad0.72x0.64mm_HandSolder
U1: MP1584EN_Buck_Module
U2: WEMOS_D1_mini_light
U3: PinHeader_1x10_P2.54mm_Vertical

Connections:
+3V3: U2.8, U3.1
+5V: U1.3, U2.9
/+19V: J1.1, J2.1, U1.1
/ADC_A0: C3.1, R2.2, U3.7
/I_SENSE: J2.2, R1.1, R2.1
/SCL: U2.14, U3.3
/SDA: U2.13, U3.4
GND: C3.2, J1.2, R1.2, U1.2, U1.4, U2.10, U3.2

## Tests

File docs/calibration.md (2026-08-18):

# Calibration

The values shipped in the ESPHome configuration are the **theoretical**
transfer curve. They assume an exact 100 Ω burden, an exact 4.000 mA zero, and
no gain error in the ADC. None of those hold precisely.

Two-point calibration corrects all three in one step. It takes ten minutes and
is the difference between an indication and a measurement.

---

## What the theoretical curve assumes

At 100 Ω burden with a 0–3 m probe:

| Level | Current | Voltage |
|---|--:|--:|
| 0 cm | 4 mA | 0.400 V |
| 300 cm | 20 mA | 2.000 V |

Real-world deviations:

| Source | Typical error |
|---|---|
| Burden resistor tolerance (0.1 %) | ±0.1 % |
| Burden resistor tolerance (1 %) | ±1 % |
| Probe zero offset | ±0.2 % FS |
| Probe span error | ±0.3 % FS |
| ADS1115 gain error | ±0.15 % |

With a 0.1 % burden these stack to well under 1 %. With a 1 % carbon resistor,
the resistor alone dominates everything else — which is why the BOM specifies
metal film at 0.1 %.

---

## Procedure

### What you need

- Multimeter
- Tape measure
- Access to the probe before it is finally installed

### Step 1 — zero point, probe in air

Power the system with the probe hanging in air, not submerged.

Measure **across R1**, the burden resistor. On the v1.1 interface board R1 is
the axial through-hole part next to the probe terminal, so its leads take meter
probes directly — the dedicated test points from the v1.0 specification were
dropped along with the rest of the protection circuitry.

Alternatively read `sensor.zisterne_pegel_sonde_rohspannung` in Home Assistant,
which is the same node measured by the ADC itself. That avoids a trip to the
shed, though a meter is the better reference when you are establishing the
calibration in the first place.

> Expected: close to 0.400 V. If you read 0.000 V, the loop is open — check
> polarity and supply. If you read more than 0.6 V, something is wrong before
> you go any further.

### Step 2 — span point, probe at known depth

Lower the probe into water to a **measured** depth. Deeper is better; use at
least half the range if you can.

Measure the depth from the water surface to the **probe's diaphragm**, not to
the cable entry or the top of the housing. The diaphragm is at the tip, behind
the protective cap.

Note voltage and depth.

### Step 3 — enter both points

In `esphome/zisterne-pegel.yaml`, replace:

```yaml
      - calibrate_linear:
          - 0.400 -> 0.0
          - 2.000 -> 300.0
```

with your measured pairs, for example:

```yaml
      - calibrate_linear:
          - 0.412 -> 0.0        # measured in air
          - 1.243 -> 155.0      # measured at 155 cm
```

ESPHome extrapolates linearly beyond the two points, so you do not need a
measurement at full scale.

### Step 4 — verify

Flash, then compare the reported centimetre value against the tape measure at a
third depth. Deviation should be within a centimetre or two.

---

## Alternative: calibrate in place

If the probe is already installed and cannot easily be removed:

**Zero point** — wait until the cistern is at a level you can measure directly,
for instance with a weighted tape from the shaft opening. Note the voltage and
the actual water column above the probe.

**Span point** — repeat at a substantially different level. Rain or a heavy
irrigation cycle will provide one within a few days.

Two points at least a metre apart give a usable calibration. Closer together,
and any measurement error in the depth reading is amplified in the slope.

---

## Sanity checks

After calibration, confirm:

| Check | Expected |
|---|---|
| Probe in air | 0 cm ± 2 cm |
| Reading vs tape measure | within 2 cm |
| Loop disconnected | fault sensor active, 0 V |
| Reading over 24 h without inflow or draw | stable within a few cm |

The last one is worth doing. A reading that drifts overnight with no water
movement points at a temperature effect or a partially blocked capillary.

---

## Cross-checking against a float ladder

If you are replacing a float switch ladder, keep it connected for a few weeks.
Its contacts sit at known heights, so each transition is a free calibration
check:

| Float contact | Known level | Probe should read |
|---|---|---|
| tank10 | 300 L | … |
| tank20 | 600 L | … |

If probe and ladder disagree by more than one step, one of them is wrong — and
you have a way to find out which.

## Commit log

2026-08-18 Add cistern level sensor interface board (KiCAD)
    Carrier board interfacing a 4-20 mA hydrostatic level probe to an ESP8266
    running ESPHome, for a garden cistern.
    Design is a carrier for three off-the-shelf modules (Wemos D1 mini, KY-053
    ADS1115 breakout, MP1584EN buck) plus three discrete parts, fed from a single
    19 V supply via screw terminals.
    - Schematic: ERC clean, netlist verified against intent
    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
    [cistern-level-interface-B_Courtyard.gbr, cistern-level-interface-B_Cu.gbl, cistern-level-interface-B_Fab.gbr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]
2026-08-18 Add project documentation and ESPHome config; reconcile with as-built board
    Organises the project research into docs/, esphome/ and images/, adds a root
    README, and fixes the discrepancies between the written record and the board
    that was actually built.
    Structure:
    docs/hardware.md BOM, wiring, probe selection, installation
    docs/pcb-specification.md interface board spec
    docs/calibration.md two-point calibration procedure
    docs/home-assistant.md entities, cards, derived sensors, automations
    docs/findings.md measured open-bottomed cistern behaviour
    esphome/ device config + secrets template
    images/ shot li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
2026-08-18 Update rule severities and enhance ERC settings in KiCAD project
